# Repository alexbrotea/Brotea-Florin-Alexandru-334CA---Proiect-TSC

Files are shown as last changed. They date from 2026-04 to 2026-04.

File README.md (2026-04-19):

## 1. Diagrama bloc

Mai jos este diagrama bloc a sistemului, ilustrand modul in care componentele interactioneaza cu unitatea centrala (MCU):

```mermaid
graph TD
    BATT[Baterie LiPo] -->|V_BATT| CHG[LiPo Charger MCP73831]
    USB[USB-C Connector] -->|5V| CHG
    CHG --> DCDC[DC/DC Converter]
    DCDC -->|3.3V| MCU(nRF52840 MCU)
    
    BATT -->|Monitorizare| FG[Fuel Gauge MAX17048]
    FG <-->|I2C| MCU
    
    MCU <-->|I2C| IMU[Senzor IMU BMI270]
    MCU <-->|I2C| HAP[Haptic Driver DRV2605L]
    
    MCU <-->|SPI| EPD_CON[E-Paper Display Connector]
    MCU -->|Control| EPD_DRV[E-Paper Drive Circuit]
    
    BTN[Butoane SW_UP, SW_ENT, SW_DN] -->|GPIO| MCU
    SWD[SWD Interface] <-->|Debug| MCU
```
## 2. Bill of Materials

| Componenta / Modul | Rol in proiect | Cod piesa JLCPCB |
|---|---|---|
| nRF52840 | Microcontroler cu Bluetooth LE | C138981 |
| MAX17048G+T10 | Fuel Gauge (monitorizare baterie) | C149814 |
| BMI270 | IMU 6 axe (accelerometru + giroscop) | C2828345 |
| DRV2605L | Driver haptic (LRA/ERM) | C78152 |
| MCP73831T-2ACI/OT | Incarcator LiPo | C14434 |
| TPD4E05U06DQNR | Protectie ESD (USB-C) | C127411 |

## 3. Functionalitate Hardware

InkTime este construit ca un sistem modular eficient energetic:

### Microcontroller (MCU)
- nRF52840 (ARM Cortex-M4F)
- Bluetooth 5 integrat
- Conectivitate directa cu smartphone

### Alimentare si Incarcare
- Incarcare prin USB-C
- Incarcator dedicat LiPo (MCP73831)
- Protectie ESD integrata
- Monitorizare baterie prin MAX17048:
  - Masoara tensiunea
  - Estimeaza procentul bateriei
  - Consum foarte redus

### Afisaj E-Paper
- Conector FPC cu 24 pini
- Circuit dedicat de drive:
  - MOSFET-uri
  - Retea de condensatori
- Genereaza tensiuni pozitive si negative necesare refresh-ului

### Interfata Utilizator
- 3 butoane:
  - SW_UP
  - SW_ENT
  - SW_DN
- Debouncing hardware
- Feedback haptic:
  - Driver DRV2605L
  - Motor vibratii (LRA/ERM)
- IMU pentru detectarea miscarii mainii

## 4. Mapare pini (Pinout nRF52840)
| Periferic | Semnal | Pin MCU | Descriere |
| --- | --- | --- | --- |
| I2C Bus | SDA / SCL | P0.26 / P0.27 | Magistrala comuna pentru senzori |
| E-Paper SPI | SCK / MOSI | P0.17 / P0.20 | Transfer rapid de date |
| E-Paper Control | CS / DC / RST / BUSY | P0.22 / P0.24 / P0.15 / P0.13 | Control display |
| Butoane | SW_UP / SW_ENT / SW_DN | P0.06 / P0.08 / P0.12 | Input cu intreruperi |
| Haptic | EN / IN | P0.05 | Activare driver haptic |
| USB Sense | VBUS | P0.02 | Detectare cablu USB |

## 5. Design Log & Review
- Placa pe 2 straturi
- Forma ergonomica adaptata carcasei
- Plan de masa optimizat pentru:
stabilitate RF
performanta Bluetooth
- Grosime minimizata
- Layout compact
- Integrare eficienta

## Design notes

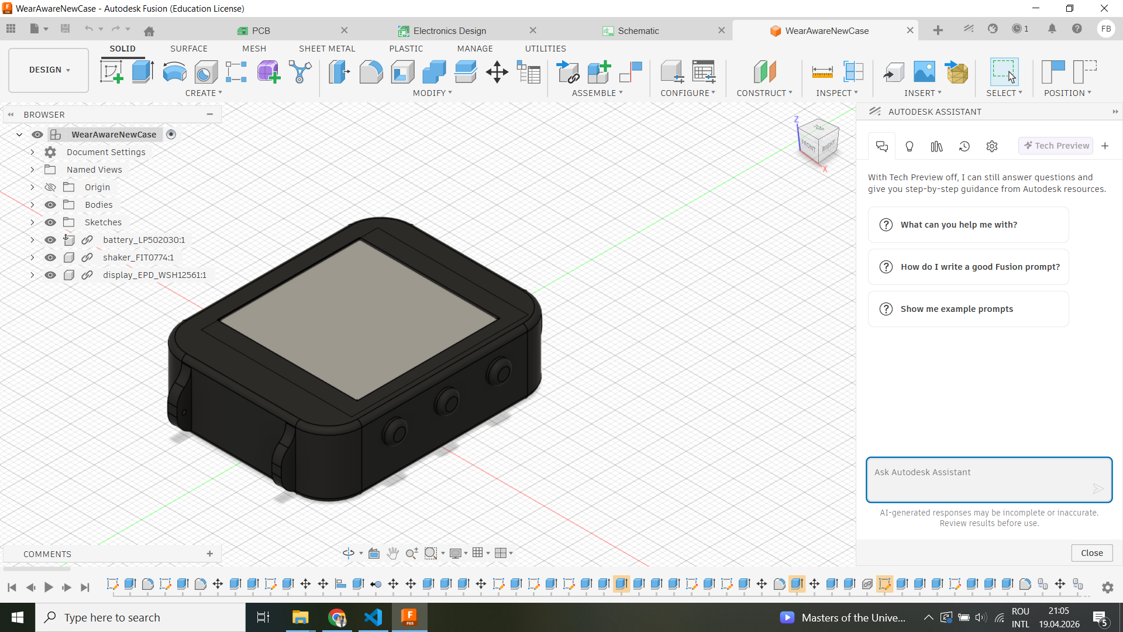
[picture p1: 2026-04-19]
Images/Screenshot (1024).png

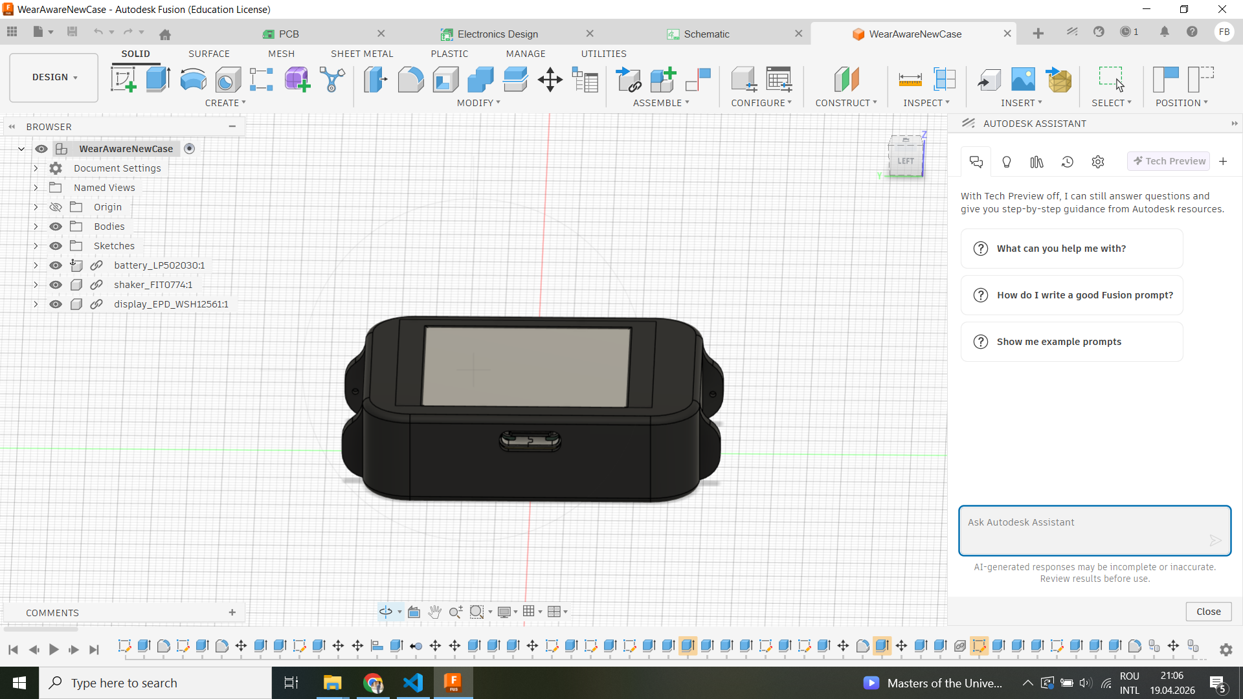
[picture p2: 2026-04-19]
Images/Screenshot (1026).png

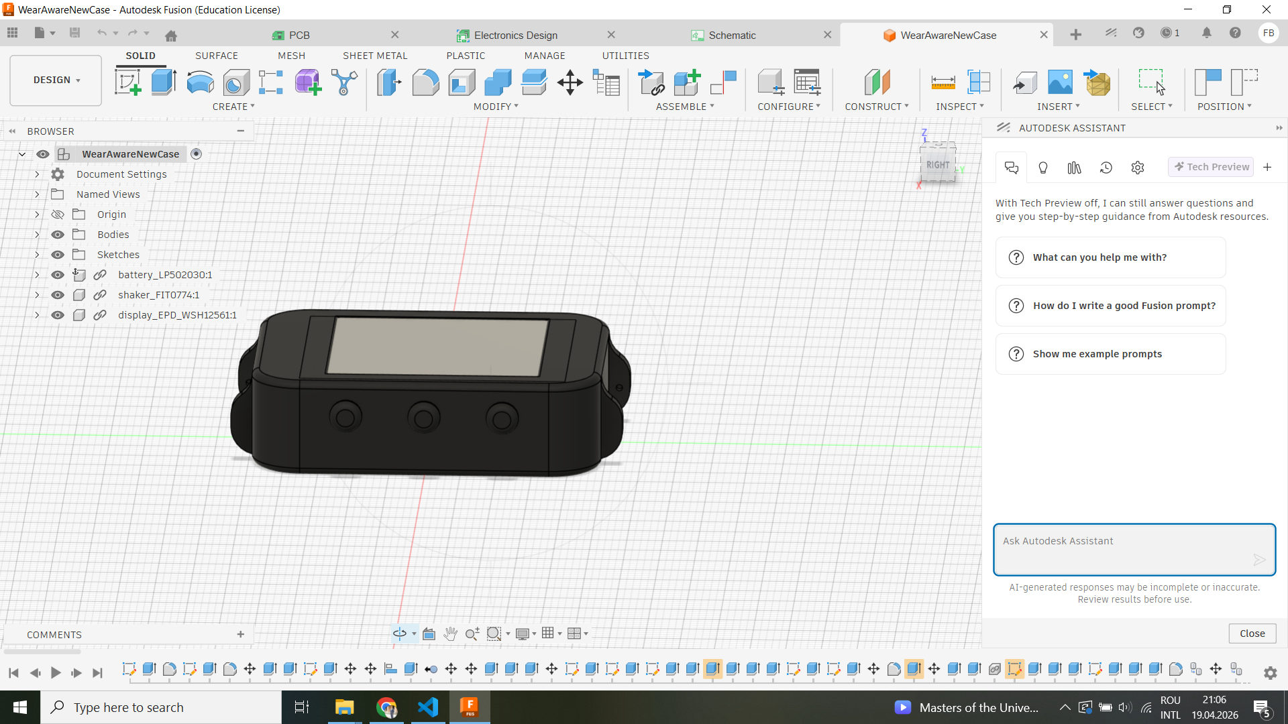
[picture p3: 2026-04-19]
Images/Screenshot (1027).png

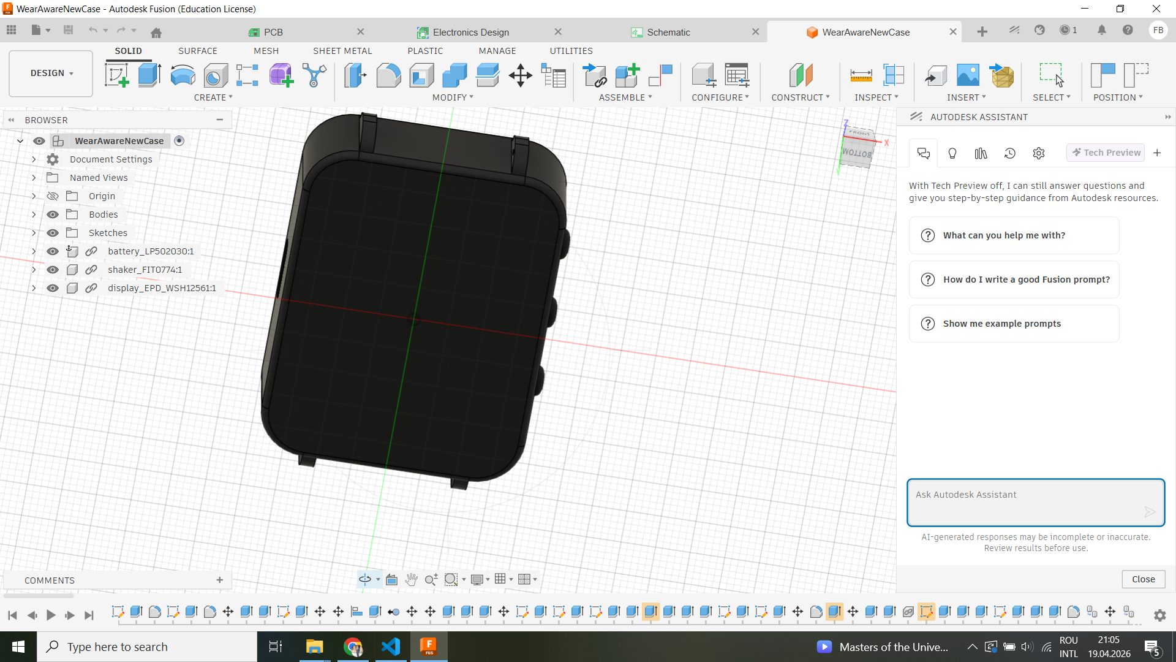
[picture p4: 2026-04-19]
Images/Screenshot (1025).png

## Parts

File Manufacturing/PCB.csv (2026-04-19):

Qty | Value | Device | Package | Parts | Description | ARROW_PART_NUMBER | ARROW_PRICE-STOCK | AVAILABILITY | CHECK_PRICES | COPYRIGHT | DESCRIPTION | DIGI-KEY_PART_NUMBER_1 | DIGI-KEY_PART_NUMBER_2 | DIGI-KEY_PART_NUMBER_3 | HEIGHT | JLCPCB | MANUFACTURER_NAME | MANUFACTURER_PART_NUMBER | MF | MFR_NAME | MOUSER_PART_NUMBER | MOUSER_PRICE-STOCK | MP | PACKAGE | POPULARITY | PRICE | PROD_ID | PURCHASE-URL | SNAPEDA_LINK | SPICEMODEL | SPICEPREFIX | TP_SIGNAL_NAME | VALUE
1 | 0 | ESP32_C6_LIBRARY_7_JUMPER_SJ | ESP32_C6_LIBRARY_7_JUMPER_SJ | SJ1 | SMD solder JUMPER |  |  |  |  |  |  |  |  |  |  |  |  |  |  |  |  |  |  |  | 3
1 | 0.1uF | GRM011R60J152KE01L_1_GRM011R60J152KE01L | GRM011R60J152KE01L_1_0201 | C4 | Check availability
1 | 0.1uF | NORDIC_NRF_3_CAPACITOR_0402_M | NORDIC_NRF_3_RESC0402_M | C23 | Generic chip capacitor
1 | 0.1uF/50V | NORDIC_NRF_3_CAPACITOR_0402_M | NORDIC_NRF_3_RESC0402_M | EPD_C5 | Generic chip capacitor
4 | 100nF | NORDIC_NRF_3_CAPACITOR_0402_M | NORDIC_NRF_3_RESC0402_M | C7, C8, CC5, CC19 | Generic chip capacitor
2 | 100pF | NORDIC_NRF_3_CAPACITOR_0402_M | NORDIC_NRF_3_RESC0402_M | C12, CC11 | Generic chip capacitor
1 | 10K | CPF0201D7K68C1_CPF0201D7K68C1 | CPF0201D7K68C1_0201 | R1 | 7.68k 0201 Thin Film Surface Mount Fixed Resistor +/-0.5% 0.031W CPF0201D7K68C1
3 | 10uF | NORDIC_NRF_3_CAPACITOR_0402_M | NORDIC_NRF_3_RESC0402_M | C1-EP-DR, C24, C39 | Generic chip capacitor
1 | 10uH | NORDIC_NRF_2_INDUCTOR_0402_M | NORDIC_NRF_2_RESC0402_M | LL2 | Generic chip inductor
4 | 12pF | NORDIC_NRF_3_CAPACITOR_0402_M | NORDIC_NRF_3_RESC0402_M | C17, C18, CC1, CC2 | Generic chip capacitor
1 | 15uH | NORDIC_NRF_2_INDUCTOR_0402_M | NORDIC_NRF_2_RESC0402_M | LL3 | Generic chip inductor
2 | 1pF | NORDIC_NRF_3_CAPACITOR_0402_M | NORDIC_NRF_3_RESC0402_M | CC3, CC4 | Generic chip capacitor
1 | 1uF | GRM011R60J152KE01L_1_GRM011R60J152KE01L | GRM011R60J152KE01L_1_0201 | C3 | Check availability
3 | 1uF | NORDIC_NRF_3_CAPACITOR_0402_M | NORDIC_NRF_3_RESC0402_M | C15, C37, C38 | Generic chip capacitor
9 | 1uF/50V | NORDIC_NRF_3_CAPACITOR_0402_M | NORDIC_NRF_3_RESC0402_M | EPD_C1, EPD_C2, EPD_C6, EPD_C7, EPD_C8, EPD_C9, EPD_C10, EPD_C11, EPD_C12 | Generic chip capacitor
3 | 2025-10-22_07-23-44_LIBRARY_EVP-AKE31ASW_EVP-AKE31A_PAN | 2025-10-22_07-23-44_LIBRARY_EVP-AKE31ASW_EVP-AKE31A_PAN | 2025-10-22_07-23-44_LIBRARY_SW_EVP-AKE31A_PAN | SW1, SW2, SW3 |  |  |  |  |  | Copyright (C) 2025 Ultra Librarian. All rights reserved. |  | P123437TR-ND | P123437CT-ND | P123437DKR-ND |  |  | Panasonic | EVP-AKE31A
1 | 20V/4.2A/52m?/1.4W | ESP32_C6_LIBRARY_4_ESP32_WROVER_SPARKFUN-DISCRETESEMI_MOSFET_PCH-DMG2305UX-7 | ESP32_C6_LIBRARY_4_ESP32_C6_LIBRARY_4_ESP32_C6_LIBRARY_4_ESP32_C6_LIBRARY_4_ESP32_WROVER_SPARKFUN-DISCRETESEMI_SOT23-3 | Q1 | P-channel MOSFETs |  |  |  |  |  |  |  |  |  |  |  |  |  |  |  |  |  |  |  |  |  | TRAN-14388 |  |  |  |  |  | 20V/4.2A/52m?/1.4W
2 | 22uF | NORDIC_NRF_3_CAPACITOR_0402_M | NORDIC_NRF_3_RESC0402_M | C25, C33 | Generic chip capacitor
1 | 2450AT18B100E_2450AT18B100E | 2450AT18B100E_2450AT18B100E | 2450AT18B100E_ANTC3216X140N | ANT1 | Antennas 2.45GHz ANTENNA | 2450AT18B100E | https://www.arrow.com/en/products/2450at18b100e/johanson-dielectrics?utm_currency=USD&region=nac |  |  |  | Antennas 2.45GHz ANTENNA |  |  |  | 1.4mm |  | JOHANSON TECHNOLOGY | 2450AT18B100E |  |  | 609-2450AT18B100E | https://www.mouser.co.uk/ProductDetail/Johanson-Technology/2450AT18B100E?qs=yCnrNFeXz%252Bh5MFsFIXGZGA%3D%3D
1 | 3.9nH | NORDIC_NRF_2_INDUCTOR_0402_M | NORDIC_NRF_2_RESC0402_M | LL1 | Generic chip inductor
1 | 32.768KHz | NORDIC_NRF_1_XTAL_32KHZ | NORDIC_NRF_1_XTAL_3215_N | X2
1 | 32MHz | NORDIC_NRF_XTAL_32MHZ | NORDIC_NRF_BT-XTAL_2016_N | X1
5 | 4.7uF | NORDIC_NRF_3_CAPACITOR_0402_M | NORDIC_NRF_3_RESC0402_M | C6, C20, C21, C43, CC14 | Generic chip capacitor
1 | 4.7uF/25V | ESP32_C6_LIBRARY_1_ESP32_WROVER_EAGLE-LTSPICE_CC0402 | ESP32_C6_LIBRARY_1_ESP32_WROVER_EAGLE-LTSPICE_C0402 | C2-EP-DR | CAPACITOR, European symbol |  |  |  |  |  |  |  |  |  |  |  |  |  |  |  |  |  |  |  |  |  |  |  |  | NONE | C
1 | 47nF | NORDIC_NRF_3_CAPACITOR_0402_M | NORDIC_NRF_3_RESC0402_M | C16 | Generic chip capacitor
1 | 503480-2400_503480-2400 | 503480-2400_503480-2400 | 503480-2400_5034802400 | J2 | FFC & FPC Connectors 0.5mm FPC RA SMT Dual Contact 24Ckt |  |  |  |  |  | FFC & FPC Connectors 0.5mm FPC RA SMT Dual Contact 24Ckt |  |  |  | 1.87mm |  | Molex | 503480-2400 |  |  | 538-503480-2400 | https://www.mouser.co.uk/ProductDetail/Molex/503480-2400?qs=OAhjpuo3Vu7efIoxFh9AOw%3D%3D
1 | 820pF | NORDIC_NRF_3_CAPACITOR_0402_M | NORDIC_NRF_3_RESC0402_M | C9 | Generic chip capacitor
1 | BMA423_BMA423 | BMA423_BMA423 | BMA423_BMA423 | IC3 | Accelerometers Triaxial low-g 12bit Acceleration Sensor | BMA423 | https://www.arrow.com/en/products/bma423/bosch |  |  |  | Accelerometers Triaxial low-g 12bit Acceleration Sensor |  |  |  | 1mm |  | BOSCH | BMA423 |  |  | 262-BMA423 | https://www.mouser.co.uk/ProductDetail/Bosch-Sensortec/BMA423?qs=HXFqYaX1Q2xC%252BSgeGoX3mg%3D%3D
1 | BQ25180YBGR_BQ25180YBGR | BQ25180YBGR_BQ25180YBGR | BQ25180YBGR_BGA8C40P2X4_100X155X50 | IC1 | Charger IC Lithium Ion/Polymer, Lithium Iron Phosphate 8-DSBGA (1.6x1.1) | BQ25180YBGR | https://www.arrow.com/en/products/bq25180ybgr/texas-instruments?utm_currency=USD&region=nac |  |  |  | Charger IC Lithium Ion/Polymer | Lithium Iron Phosphate 8-DSBGA (1.6x1.1) |  |  |  | 0.5mm |  | Texas Instruments | BQ25180YBGR |  |  | 595-BQ25180YBGR | https://www.mouser.co.uk/ProductDetail/Texas-Instruments/BQ25180YBGR?qs=doiCPypUmgEWjAK%252BJAX6Tw%3D%3D
14 | CPF0201D7K68C1_CPF0201D7K68C1 | CPF0201D7K68C1_CPF0201D7K68C1 | CPF0201D7K68C1_0201 | R2, R3, R4, R5, R6, R7, R8, R9, R10, R11, R12, R13, R14, R15 | 7.68k 0201 Thin Film Surface Mount Fixed Resistor +/-0.5% 0.031W CPF0201D7K68C1
1 | DRV2605YZFR_DRV2605YZFR | DRV2605YZFR_DRV2605YZFR | DRV2605YZFR_BGA9C50P3X3_144X144X62 | IC4 | Haptic Driver for ERM/LRA with Built-In Library and Smart Loop Architecture | DRV2605YZFR | https://www.arrow.com/en/products/drv2605yzfr/texas-instruments?region=nac |  |  |  | Haptic Driver for ERM/LRA with Built-In Library and Smart Loop Architecture |  |  |  | 0.625mm |  | Texas Instruments | DRV2605YZFR
1 | ESP32_C6_LIBRARY_2_744043680IND_4828-WE-TPC_WRE | ESP32_C6_LIBRARY_2_744043680IND_4828-WE-TPC_WRE | ESP32_C6_LIBRARY_2_IND_4828-WE-TPC_WRE | L2 |  |  |  |  |  | Copyright (C) 2024 Ultra Librarian. All rights reserved. |  |  |  |  |  |  |  | 744043680 |  | Wurth Electronics
1 | ESP32_C6_LIBRARY_3_USBLC6-2SC6Y | ESP32_C6_LIBRARY_3_USBLC6-2SC6Y | ESP32_C6_LIBRARY_3_SOT95P280X145-6N | D4 | Low Cap. ESD Protection Auto SOT-23-6 STMicroelectronics USBLC6-2SC6Y, Dual Uni-Directional TVS Diode Array, 6-Pin SOT-23 |  |  | In Stock | https://www.snapeda.com/parts/USBLC6-2SC6Y/STMicroelectronics/view-part/?ref=eda |  | 17V Clamp 5A (8/20µs) Ipp Tvs Diode Surface Mount SOT-23-6 |  |  |  |  |  |  |  | STMicroelectronics |  |  |  | USBLC6-2SC6Y | SOT-23-6 STMicroelectronics |  | None |  |  | https://www.snapeda.com/parts/USBLC6-2SC6Y/STMicroelectronics/view-part/?ref=snap
3 | ESP32_C6_LIBRARY_5_MBR0530 | ESP32_C6_LIBRARY_5_MBR0530 | ESP32_C6_LIBRARY_5_SOD3716X135N | D1, D2, D3 | ON SEMICONDUCTOR - MBR0530 - DIODE, SCHOTTKY, 0.5A, 30V, SOD-123 |  |  | In Stock | https://www.snapeda.com/parts/MBR0530/Onsemi/view-part/?ref=eda |  | Diode Schottky 30 V 500mA Surface Mount SOD-123 |  |  |  |  |  |  |  | ON Semiconductor |  |  |  | MBR0530 | SOD-123-2 ON Semiconductor |  | None |  | https://www.snapeda.com/api/url_track_click_mouser/?unipart_id=179458&manufacturer=ON Semiconductor&part_name=MBR0530&search_term=None | https://www.snapeda.com/parts/MBR0530/Onsemi/view-part/?ref=snap
1 | ESP32_C6_LIBRARY_6_SI1308EDL-T1-GE3 | ESP32_C6_LIBRARY_6_SI1308EDL-T1-GE3 | ESP32_C6_LIBRARY_6_SOT65P210X110-3N | Q2 | MOSFET N-Ch 30V 1.5A TrenchFET SC70 Vishay Si1308EDL-T1-GE3 N-channel MOSFET Transistor, 1.5 A, 30 V, 3-Pin SC-70 |  |  | In Stock | https://www.snapeda.com/parts/SI1308EDL-T1-GE3/Vishay+Siliconix/view-part/?ref=eda |  | Si1308EDL-T1-GE3 N-channel MOSFET Transistor | 1.5 A | 30 V | 3-Pin SC-70 | Siliconix / Vishay SI1308EDL-T1-GE3 |  |  |  |  |  |  |  | Vishay Siliconix |  |  |  | SI1308EDL-T1-GE3 | SOT-323 Vishay Semiconductor |  | None |  | https://www.snapeda.com/api/url_track_click_mouser/?unipart_id=274603&manufacturer=Vishay Siliconix&part_name=SI1308EDL-T1-GE3&search_term=None | https://www.snapeda.com/parts/SI1308EDL-T1-GE3/Vishay+Siliconix/view-part/?ref=snap
1 | ESP32_C6_LIBRARY_MAX17048G+T10 | ESP32_C6_LIBRARY_MAX17048G+T10 | ESP32_C6_LIBRARY_SON50P200X200X80-9N | U1 | Check availability |  |  | In Stock | https://www.snapeda.com/parts/MAX17048G+T10/Analog+Devices/view-part/?ref=eda |  | 3µA 1-Cell/2-Cell Fuel Gauge with ModelGauge |  |  |  |  |  |  |  | Analog Devices |  |  |  | MAX17048G+T10 | TDFN-8 Maxim |  | None |  | https://www.snapeda.com/api/url_track_click_mouser/?unipart_id=329239&manufacturer=Analog Devices&part_name=MAX17048G+T10&search_term=None | https://www.snapeda.com/parts/MAX17048G+T10/Analog+Devices/view-part/?ref=snap
5 | GRM011R60J152KE01L_1_GRM011R60J152KE01L | GRM011R60J152KE01L_1_GRM011R60J152KE01L | GRM011R60J152KE01L_1_0201 | C2, C5, C10, C11, C42 | Check availability
14 | HECTOR_WATCH_1_TPTP20R | HECTOR_WATCH_1_TPTP20R | HECTOR_WATCH_1_TP20R | TP_3V3, TP_SCL, TP_SDA, TP_SDA1, TP_SDA2, TP_SDA3, TP_SDA4, TP_SDA5, TP_SDA6, TP_SDA7, TP_SDA8, TP_SDA9, TP_SDA10, TP_VREG | Test pad |  |  |  |  |  |  |  |  |  |  |  |  |  |  |  |  |  |  |  | 2
1 | KH-TYPE-C-16P_KH-TYPE-C-16P | KH-TYPE-C-16P_KH-TYPE-C-16P | KH-TYPE-C-16P_KINGHELM_KH-TYPE-C-16P | J3 | Check availability |  |  | Not in stock | https://www.snapeda.com/parts/KH-TYPE-C-16P/Kinghelm/view-part/?ref=eda |  |  |  |  |  |  |  |  |  | kinghelm |  |  |  | KH-TYPE-C-16P | None |  | None |  |  | https://www.snapeda.com/parts/KH-TYPE-C-16P/Kinghelm/view-part/?ref=snap
1 | MLP2016SR47MT0S1_FTC252012SR47MBCA | MLP2016SR47MT0S1_FTC252012SR47MBCA | MLP2016SR47MT0S1_INDC2016X100N | L1 | SMD / SMT Inductors (Coils), L=0.47?H, L x W x T : |  |  |  |  |  | SMD / SMT Inductors (Coils) | L=0.47?H | L x W x T : |  |  |  | 1mm | https://jlcpcb.com/partdetail/6763488-FTC252012SR47MBCA/C5832368 | TDK | FTC252012SR47MBCA
3 | N.C | NORDIC_NRF_3_CAPACITOR_0402_M | NORDIC_NRF_3_RESC0402_M | C13, CC10, CC22 | Generic chip capacitor
1 | NORDIC_NRF_4_NRF52840_QF | NORDIC_NRF_4_NRF52840_QF | NORDIC_NRF_4_AQFN50P700X700X85_HS-74N | P1.01/2.4B | nRF52840
1 | RT6160AWSC_RT6160AWSC | RT6160AWSC_RT6160AWSC | RT6160AWSC_BGA15C40P3X5_140X230X60 | IC2 | Buck-Boost Regulator Positive Output Step-Up/Step-Down I2C DC-DC Controller IC 15-WL-CSP (BSC) (1.4x2.3) |  |  |  |  |  | Buck-Boost Regulator Positive Output Step-Up/Step-Down I2C DC-DC Controller IC 15-WL-CSP (BSC) (1.4x2.3) |  |  |  | 0.6mm |  | RICHTEK | RT6160AWSC |  |  | 835-RT6160AWSC | https://www.mouser.co.uk/ProductDetail/Richtek/RT6160AWSC?qs=amGC7iS6iy%2FLd9PSoixZXQ%3D%3D
1 | TC2030-IDC_TC2030-IDC | TC2030-IDC_TC2030-IDC | TC2030-IDC_TC2030IDC | J1 | CABLE ADAPTER 6 POS |  |  |  |  |  | CABLE ADAPTER 6 POS |  |  |  | 19mm |  | Tag Connect | TC2030-IDC

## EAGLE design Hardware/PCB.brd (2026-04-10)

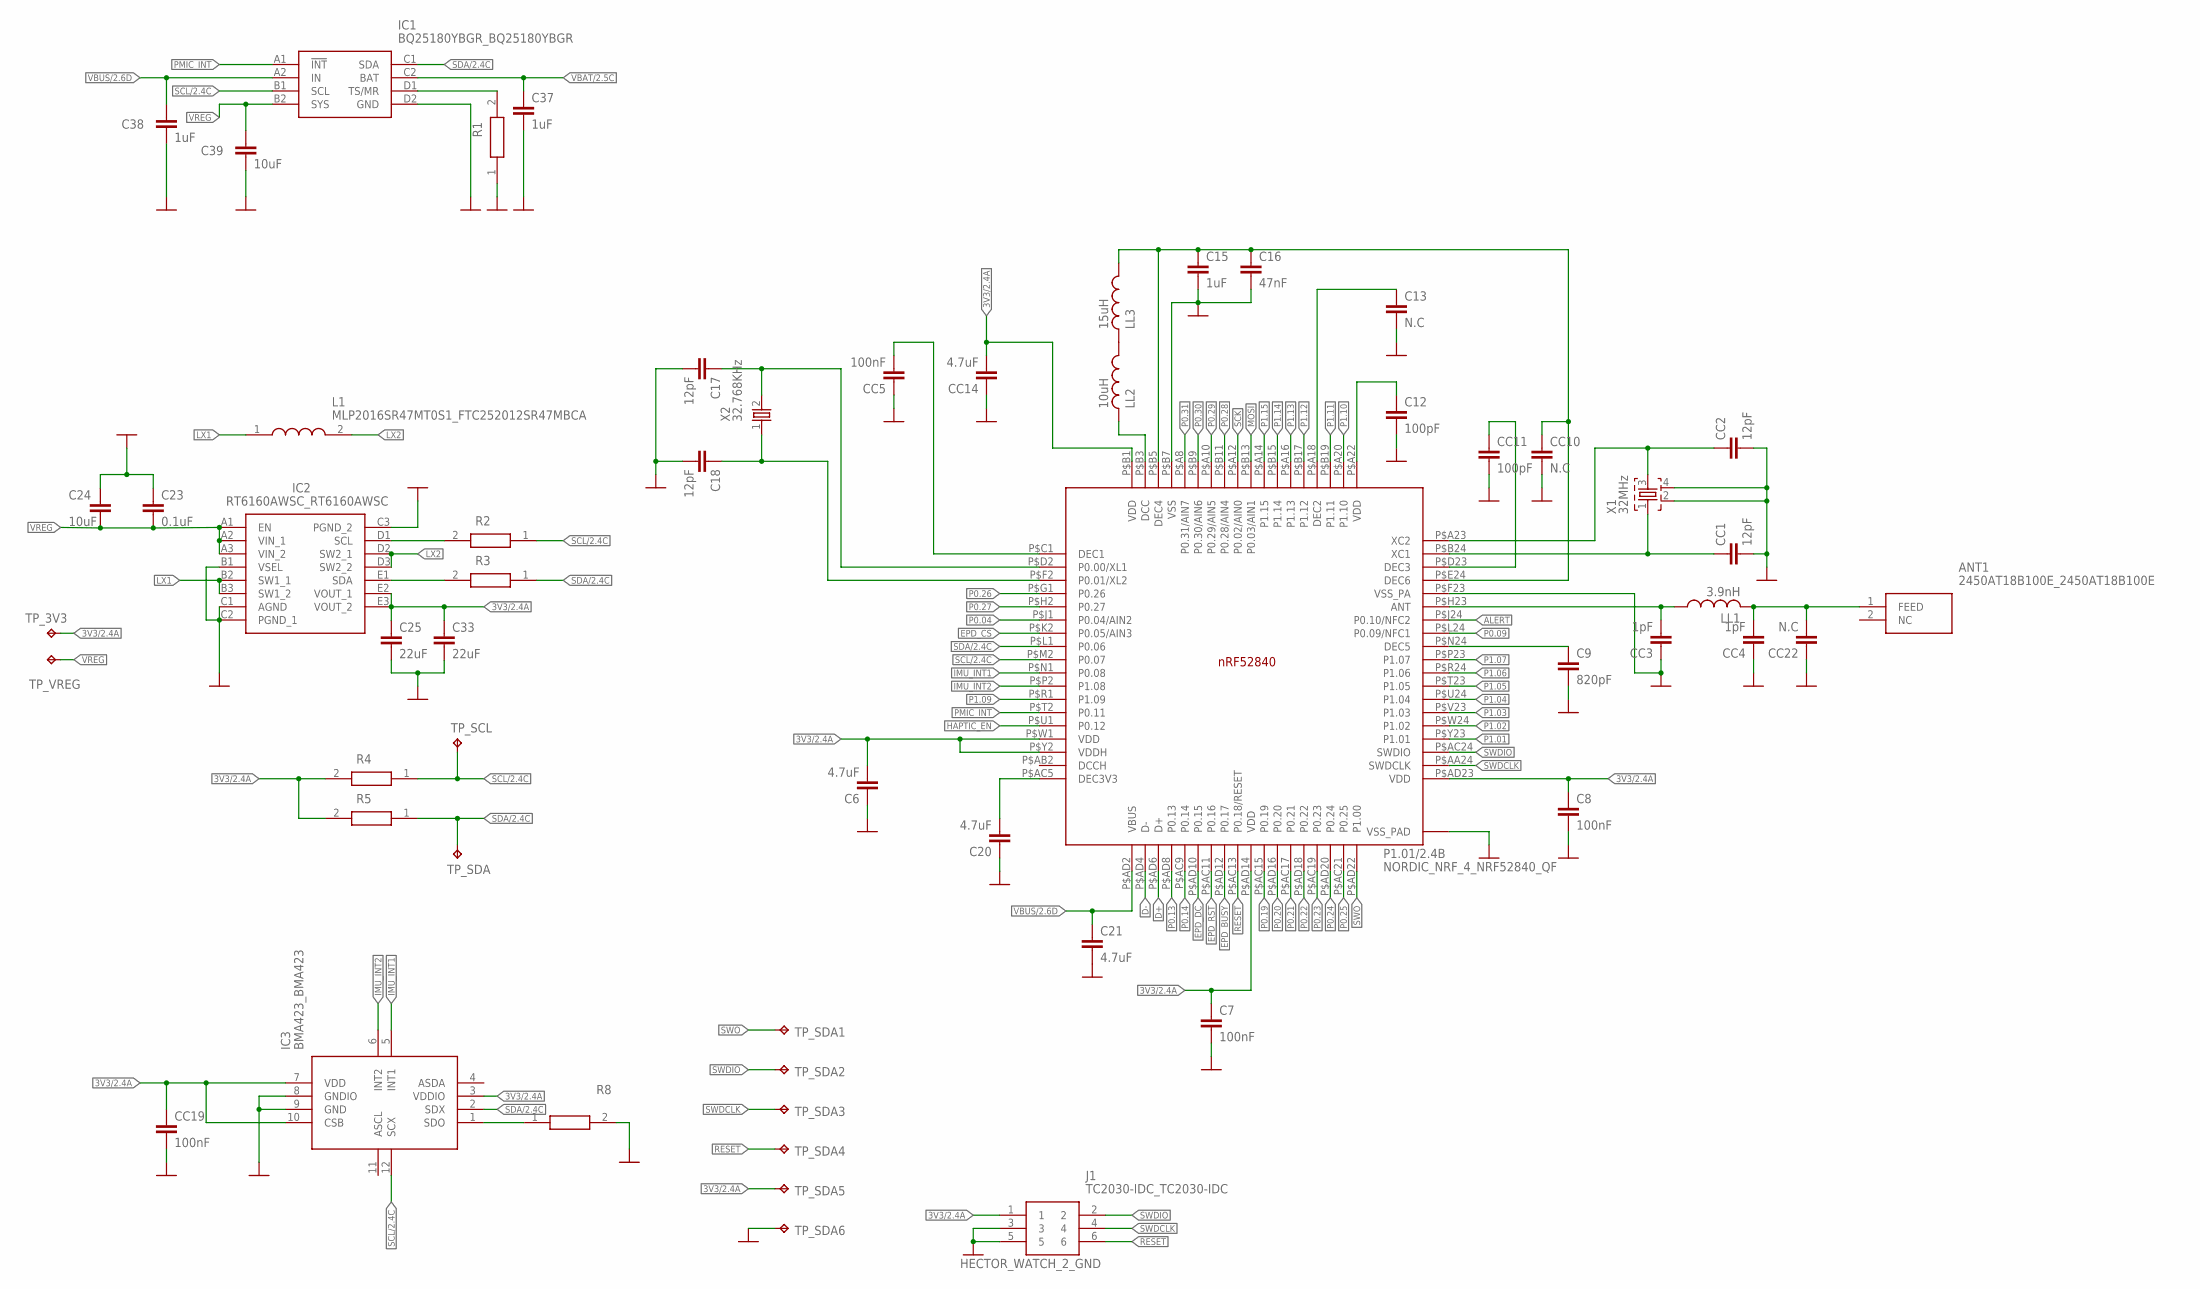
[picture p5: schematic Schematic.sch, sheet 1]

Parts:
ANT1: 2450AT18B100E_2450AT18B100E; 2450AT18B100E_ANTC3216X140N
C6, C20, C21: 4.7uF; NORDIC_NRF_3_RESC0402_M
C7, C8: 100nF; NORDIC_NRF_3_RESC0402_M
C9: 820pF; NORDIC_NRF_3_RESC0402_M
C12: 100pF; NORDIC_NRF_3_RESC0402_M
C13: N.C; NORDIC_NRF_3_RESC0402_M
C15, C37, C38: 1uF; NORDIC_NRF_3_RESC0402_M
C16: 47nF; NORDIC_NRF_3_RESC0402_M
C17, C18: 12pF; NORDIC_NRF_3_RESC0402_M
C23: 0.1uF; NORDIC_NRF_3_RESC0402_M
C24, C39: 10uF; NORDIC_NRF_3_RESC0402_M
C25, C33: 22uF; NORDIC_NRF_3_RESC0402_M
CC1, CC2: 12pF; NORDIC_NRF_3_RESC0402_M
CC3, CC4: 1pF; NORDIC_NRF_3_RESC0402_M
CC5, CC19: 100nF; NORDIC_NRF_3_RESC0402_M
CC10, CC22: N.C; NORDIC_NRF_3_RESC0402_M
CC11: 100pF; NORDIC_NRF_3_RESC0402_M
CC14: 4.7uF; NORDIC_NRF_3_RESC0402_M
IC1: BQ25180YBGR_BQ25180YBGR; BQ25180YBGR_BGA8C40P2X4_100X155X50
IC2: RT6160AWSC_RT6160AWSC; RT6160AWSC_BGA15C40P3X5_140X230X60
IC3: BMA423_BMA423
J1: TC2030-IDC_TC2030-IDC; TC2030-IDC_TC2030IDC
L1: MLP2016SR47MT0S1_FTC252012SR47MBCA; MLP2016SR47MT0S1_INDC2016X100N
LL1: 3.9nH; NORDIC_NRF_2_RESC0402_M
LL2: 10uH; NORDIC_NRF_2_RESC0402_M
LL3: 15uH; NORDIC_NRF_2_RESC0402_M
P1.01/2.4B: NORDIC_NRF_4_NRF52840_QF; NORDIC_NRF_4_AQFN50P700X700X85_HS-74N
R1: 10K; CPF0201D7K68C1_0201
R2, R3, R4, R5, R8: CPF0201D7K68C1_CPF0201D7K68C1; CPF0201D7K68C1_0201
TP_3V3: HECTOR_WATCH_1_TPTP20R; HECTOR_WATCH_1_TP20R
TP_SCL: HECTOR_WATCH_1_TPTP20R; HECTOR_WATCH_1_TP20R
TP_SDA, TP_SDA1, TP_SDA2, TP_SDA3, TP_SDA4, TP_SDA5, TP_SDA6: HECTOR_WATCH_1_TPTP20R; HECTOR_WATCH_1_TP20R
TP_VREG: HECTOR_WATCH_1_TPTP20R; HECTOR_WATCH_1_TP20R
X1: 32MHz; NORDIC_NRF_BT-XTAL_2016_N
X2: 32.768KHz; NORDIC_NRF_1_XTAL_3215_N

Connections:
3V3/2.4A: C6.2, C7.1, C8.1, C25.1, C33.1, CC14.2, CC19.1, IC2.E2 (VOUT_1), IC2.E3 (VOUT_2), IC3.3 (VDDIO), IC3.7 (VDD), IC3.10 (CSB), J1.1, P1.01/2.4B.P$AD14 (VDD), P1.01/2.4B.P$AD23 (VDD), P1.01/2.4B.P$B1 (VDD), P1.01/2.4B.P$W1 (VDD), P1.01/2.4B.P$Y2 (VDDH), R4.2, R5.2, TP_3V3.TP, TP_SDA5.TP
ALERT: P1.01/2.4B.P$J24 (P0.10/NFC2); also elsewhere on the board
D+: P1.01/2.4B.P$AD6 (D+); also elsewhere on the board
D-: P1.01/2.4B.P$AD4 (D-); also elsewhere on the board
EPD_BUSY: P1.01/2.4B.P$AD12 (P0.17); also elsewhere on the board
EPD_CS: P1.01/2.4B.P$K2 (P0.05/AIN3); also elsewhere on the board
EPD_DC: P1.01/2.4B.P$AD10 (P0.15); also elsewhere on the board
EPD_RST: P1.01/2.4B.P$AC11 (P0.16); also elsewhere on the board
GND: C6.1, C7.2, C8.2, C9.2, C12.2, C13.2, C15.2, C16.2, C17.2, C18.2, C20.1, C21.2, C23.1, C24.1, C25.2, C33.2, C37.2, C38.2, C39.2, CC1.2, CC2.2, CC3.1, CC4.1, CC5.1, CC10.2, CC11.2, CC14.1, CC19.2, CC22.1, IC1.D2 (GND), IC2.B1 (VSEL), IC2.C1 (AGND), IC2.C2 (PGND_1), IC2.C3 (PGND_2), IC3.8 (GNDIO), IC3.9 (GND), J1.3, J1.5, P1.01/2.4B.P$74 (VSS_PAD), P1.01/2.4B.P$75 (VSS_PAD), P1.01/2.4B.P$76 (VSS_PAD), P1.01/2.4B.P$77 (VSS_PAD), P1.01/2.4B.P$78 (VSS_PAD), P1.01/2.4B.P$79 (VSS_PAD), P1.01/2.4B.P$80 (VSS_PAD), P1.01/2.4B.P$81 (VSS_PAD), P1.01/2.4B.P$82 (VSS_PAD), P1.01/2.4B.P$83 (VSS_PAD), P1.01/2.4B.P$84 (VSS_PAD), P1.01/2.4B.P$85 (VSS_PAD), P1.01/2.4B.P$86 (VSS_PAD), P1.01/2.4B.P$87 (VSS_PAD), P1.01/2.4B.P$88 (VSS_PAD), P1.01/2.4B.P$89 (VSS_PAD), P1.01/2.4B.P$90 (VSS_PAD), P1.01/2.4B.P$B7 (VSS), P1.01/2.4B.P$F23 (VSS_PA), R1.1, R8.2, TP_SDA6.TP, X1.2, X1.4; also elsewhere on the board
HAPTIC_EN: P1.01/2.4B.P$U1 (P0.12); also elsewhere on the board
IMU_INT1: IC3.5 (INT1), P1.01/2.4B.P$N1 (P0.08)
IMU_INT2: IC3.6 (INT2), P1.01/2.4B.P$P2 (P1.08)
LX1: IC2.B2 (SW1_1), IC2.B3 (SW1_2), L1.1
LX2: IC2.D2 (SW2_1), IC2.D3 (SW2_2), L1.2
MOSI: P1.01/2.4B.P$B13 (P0.03/AIN1); also elsewhere on the board
unnamed: IC1.D1 (TS/MR), R1.2
unnamed: C9.1, P1.01/2.4B.P$N24 (DEC5)
unnamed: CC3.2, LL1.1, P1.01/2.4B.P$H23 (ANT)
unnamed: IC2.D1 (SCL), R2.2
unnamed: IC2.E1 (SDA), R3.2
unnamed: C20.2, P1.01/2.4B.P$AC5 (DEC3V3)
unnamed: ANT1.1 (FEED), CC4.2, CC22.2, LL1.2
unnamed: CC1.1, P1.01/2.4B.P$B24 (XC1), X1.1
unnamed: CC2.1, P1.01/2.4B.P$A23 (XC2), X1.3
unnamed: CC11.1, P1.01/2.4B.P$D23 (DEC3)
unnamed: C18.1, P1.01/2.4B.P$F2 (P0.01/XL2), X2.1
unnamed: C12.1, P1.01/2.4B.P$A22 (VDD)
unnamed: C13.1, P1.01/2.4B.P$A18 (DEC2)
unnamed: LL2.1, LL3.2
unnamed: LL2.2, P1.01/2.4B.P$B3 (DCC)
unnamed: C15.1, C16.1, CC10.1, LL3.1, P1.01/2.4B.P$B5 (DEC4), P1.01/2.4B.P$E24 (DEC6)
unnamed: C17.1, P1.01/2.4B.P$D2 (P0.00/XL1), X2.2
unnamed: IC3.1 (SDO), R8.1
unnamed: CC5.2, P1.01/2.4B.P$C1 (DEC1)
P0.04: P1.01/2.4B.P$J1 (P0.04/AIN2)
P0.09: P1.01/2.4B.P$L24 (P0.09/NFC1)
P0.13: P1.01/2.4B.P$AD8 (P0.13); also elsewhere on the board
P0.14: P1.01/2.4B.P$AC9 (P0.14); also elsewhere on the board
P0.19: P1.01/2.4B.P$AC15 (P0.19)
P0.20: P1.01/2.4B.P$AD16 (P0.20)
P0.21: P1.01/2.4B.P$AC17 (P0.21)
P0.22: P1.01/2.4B.P$AD18 (P0.22)
P0.23: P1.01/2.4B.P$AC19 (P0.23)
P0.24: P1.01/2.4B.P$AD20 (P0.24)
P0.25: P1.01/2.4B.P$AC21 (P0.25)
P0.26: P1.01/2.4B.P$G1 (P0.26)
P0.27: P1.01/2.4B.P$H2 (P0.27)
P0.28: P1.01/2.4B.P$B11 (P0.28/AIN4)
P0.29: P1.01/2.4B.P$A10 (P0.29/AIN5)
P0.30: P1.01/2.4B.P$B9 (P0.30/AIN6)
P0.31: P1.01/2.4B.P$A8 (P0.31/AIN7)
P1.01: P1.01/2.4B.P$Y23 (P1.01); also elsewhere on the board
P1.02: P1.01/2.4B.P$W24 (P1.02); also elsewhere on the board
P1.03: P1.01/2.4B.P$V23 (P1.03)
P1.04: P1.01/2.4B.P$U24 (P1.04)
P1.05: P1.01/2.4B.P$T23 (P1.05)
P1.06: P1.01/2.4B.P$R24 (P1.06)
P1.07: P1.01/2.4B.P$P23 (P1.07)
P1.09: P1.01/2.4B.P$R1 (P1.09)
P1.10: P1.01/2.4B.P$A20 (P1.10)
P1.11: P1.01/2.4B.P$B19 (P1.11)
P1.12: P1.01/2.4B.P$B17 (P1.12)
P1.13: P1.01/2.4B.P$A16 (P1.13)
P1.14: P1.01/2.4B.P$B15 (P1.14)
P1.15: P1.01/2.4B.P$A14 (P1.15)
PMIC_INT: IC1.A1 (!INT), P1.01/2.4B.P$T2 (P0.11)
RESET: J1.6, P1.01/2.4B.P$AC13 (P0.18/RESET), TP_SDA4.TP
SCK: P1.01/2.4B.P$A12 (P0.02/AIN0); also elsewhere on the board
SCL/2.4C: IC1.B1 (SCL), IC3.12 (SCX), P1.01/2.4B.P$M2 (P0.07), R2.1, R4.1, TP_SCL.TP
SDA/2.4C: IC1.C1 (SDA), IC3.2 (SDX), P1.01/2.4B.P$L1 (P0.06), R3.1, R5.1, TP_SDA.TP
SWDCLK: J1.4, P1.01/2.4B.P$AA24 (SWDCLK), TP_SDA3.TP
SWDIO: J1.2, P1.01/2.4B.P$AC24 (SWDIO), TP_SDA2.TP
SWO: P1.01/2.4B.P$AD22 (P1.00), TP_SDA1.TP
VBAT/2.5C: C37.1, IC1.C2 (BAT)
VBUS/2.6D: C21.1, C38.1, IC1.A2 (IN), P1.01/2.4B.P$AD2 (VBUS)
VREG: C23.2, C24.2, C39.1, IC1.B2 (SYS), IC2.A1 (EN), IC2.A2 (VIN_1), IC2.A3 (VIN_2), TP_VREG.TP

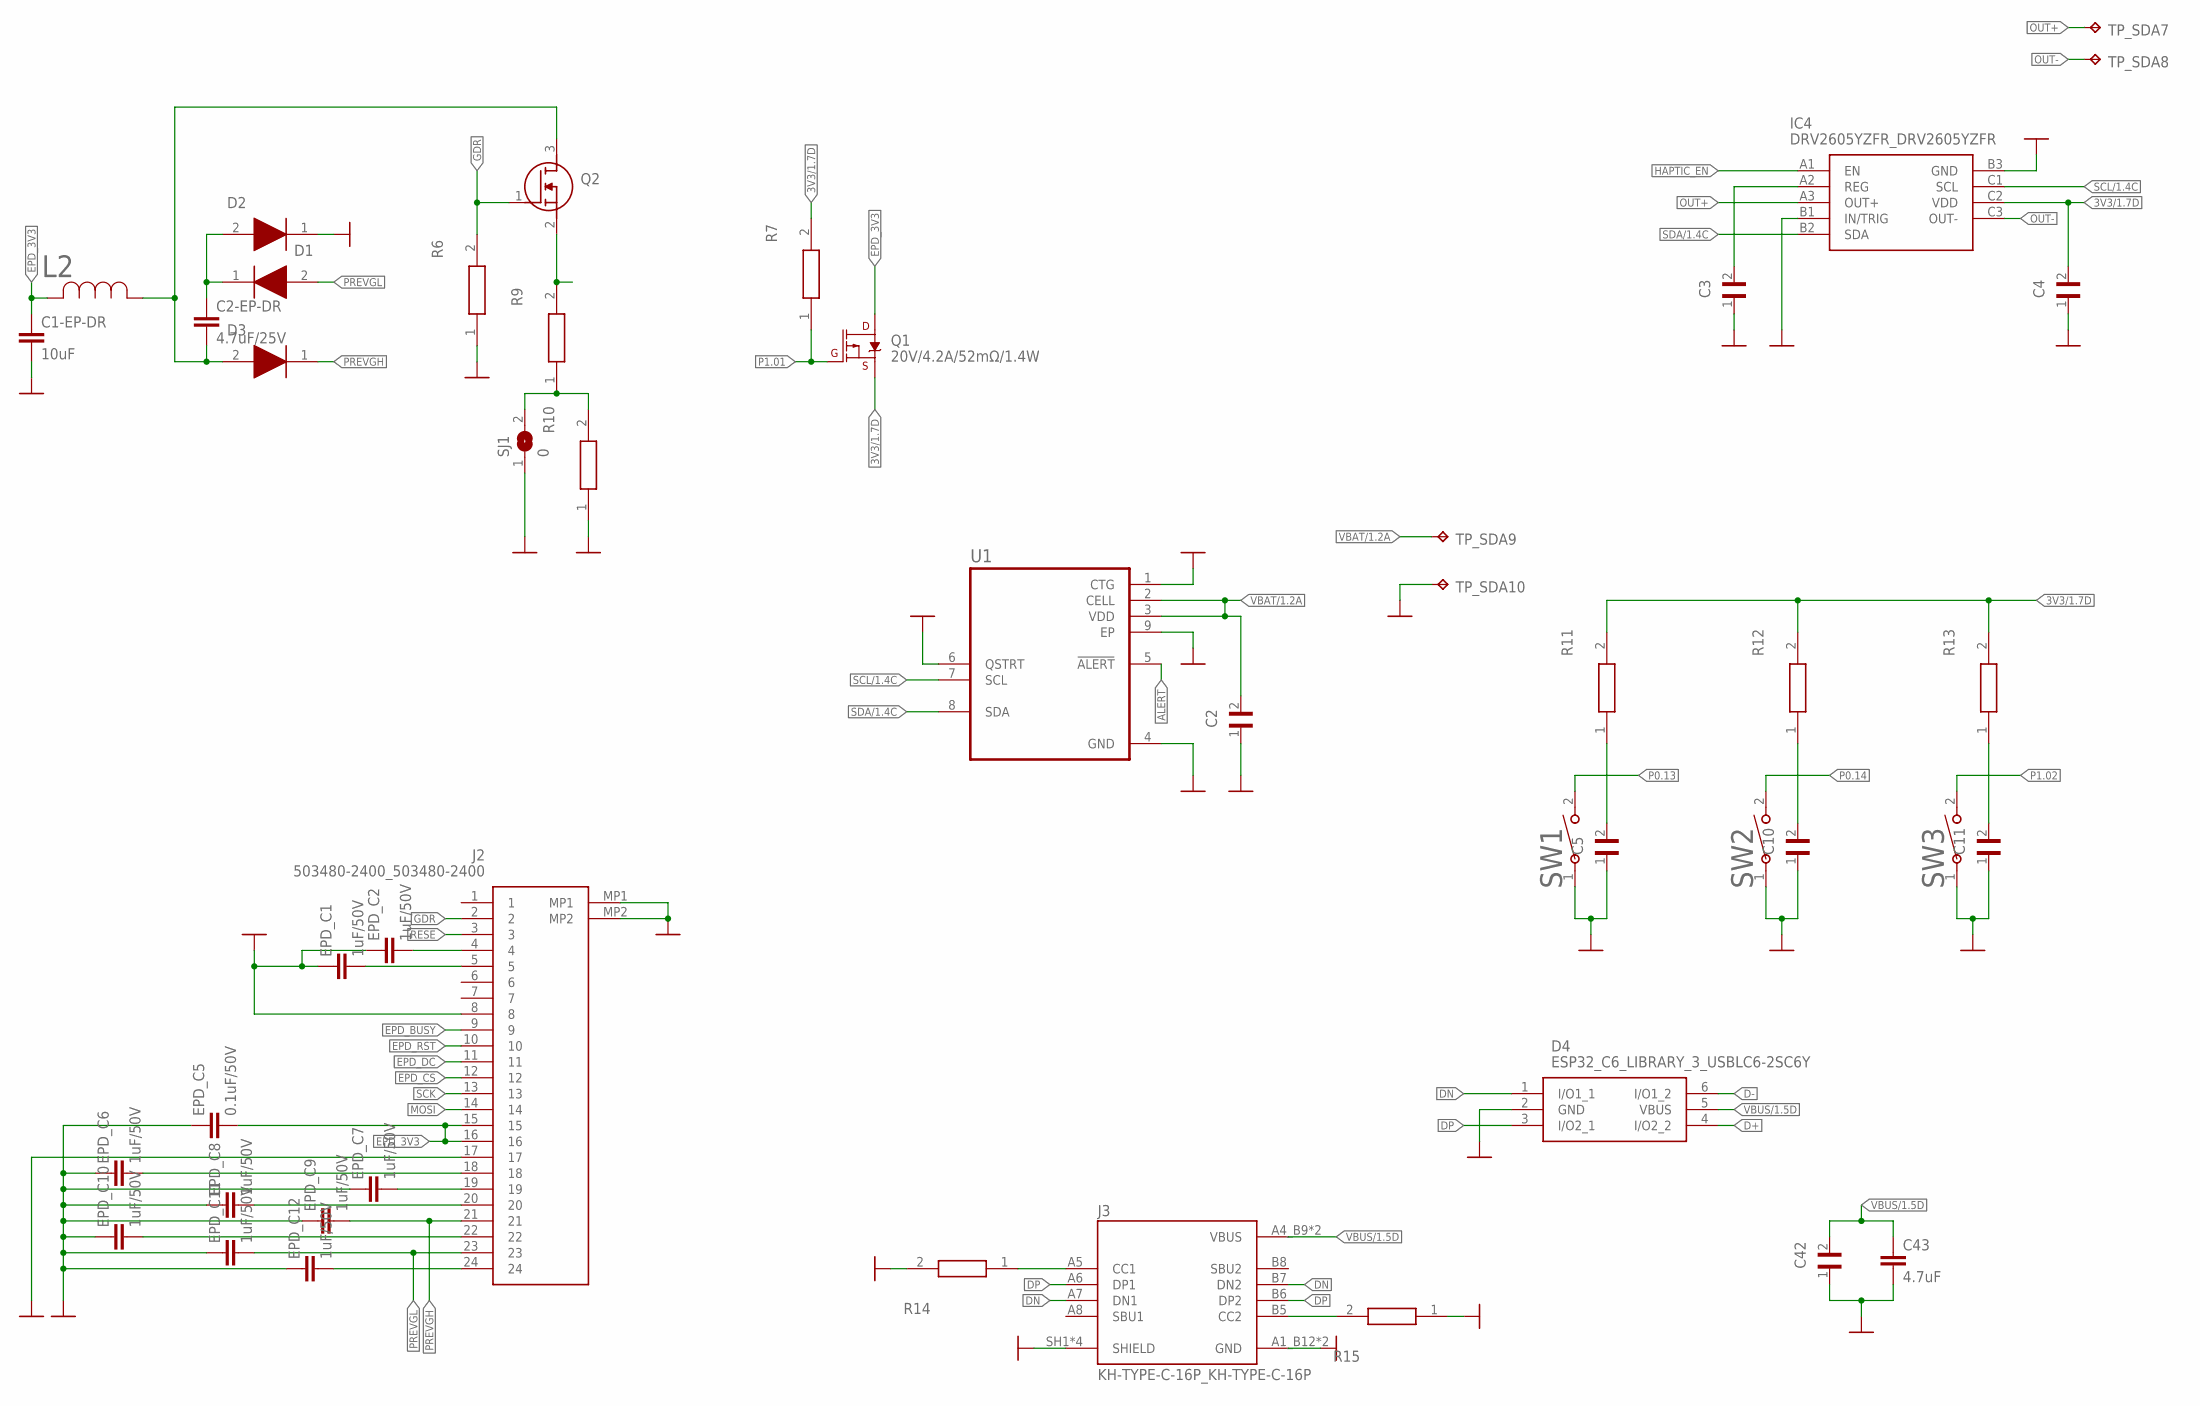
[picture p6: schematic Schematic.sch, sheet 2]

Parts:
C1-EP-DR: 10uF; NORDIC_NRF_3_RESC0402_M
C2, C5, C10, C11, C42: GRM011R60J152KE01L_1_GRM011R60J152KE01L; GRM011R60J152KE01L_1_0201
C2-EP-DR: 4.7uF/25V; ESP32_C6_LIBRARY_1_ESP32_WROVER_EAGLE-LTSPICE_C0402
C3: 1uF; GRM011R60J152KE01L_1_0201
C4: 0.1uF; GRM011R60J152KE01L_1_0201
C43: 4.7uF; NORDIC_NRF_3_RESC0402_M
D1, D2, D3: ESP32_C6_LIBRARY_5_MBR0530; ESP32_C6_LIBRARY_5_SOD3716X135N
D4: ESP32_C6_LIBRARY_3_USBLC6-2SC6Y; ESP32_C6_LIBRARY_3_SOT95P280X145-6N
EPD_C1, EPD_C2, EPD_C6, EPD_C7, EPD_C8, EPD_C9, EPD_C10, EPD_C11, EPD_C12: 1uF/50V; NORDIC_NRF_3_RESC0402_M
EPD_C5: 0.1uF/50V; NORDIC_NRF_3_RESC0402_M
IC4: DRV2605YZFR_DRV2605YZFR; DRV2605YZFR_BGA9C50P3X3_144X144X62
J2: 503480-2400_503480-2400; 503480-2400_5034802400
J3: KH-TYPE-C-16P_KH-TYPE-C-16P; KH-TYPE-C-16P_KINGHELM_KH-TYPE-C-16P
L2: ESP32_C6_LIBRARY_2_744043680IND_4828-WE-TPC_WRE; ESP32_C6_LIBRARY_2_IND_4828-WE-TPC_WRE
Q1: 20V/4.2A/52mΩ/1.4W; ESP32_C6_LIBRARY_4_ESP32_C6_LIBRARY_4_ESP32_C6_LIBRARY_4_ES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
Q2: ESP32_C6_LIBRARY_6_SI1308EDL-T1-GE3; ESP32_C6_LIBRARY_6_SOT65P210X110-3N
R6, R7, R9, R10, R11, R12, R13, R14, R15: CPF0201D7K68C1_CPF0201D7K68C1; CPF0201D7K68C1_0201
SJ1: 0; ESP32_C6_LIBRARY_7_JUMPER_SJ
SW1, SW2, SW3: 2025-10-22_07-23-44_LIBRARY_EVP-AKE31ASW_EVP-AKE3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; 2025-10-22_07-23-44_LIBRARY_SW_EVP-AKE31A_PAN
TP_SDA7, TP_SDA8, TP_SDA9, TP_SDA10: HECTOR_WATCH_1_TPTP20R; HECTOR_WATCH_1_TP20R
U1: ESP32_C6_LIBRARY_MAX17048G+T10; ESP32_C6_LIBRARY_SON50P200X200X80-9N

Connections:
3V3/1.7D: C4.2, IC4.C2 (VDD), Q1.2 (S), R7.2, R11.2, R12.2, R13.2
ALERT: U1.5 (!ALERT); also elsewhere on the board
D+: D4.4 (I/O2_2); also elsewhere on the board
D-: D4.6 (I/O1_2); also elsewhere on the board
DN: D4.1 (I/O1_1), J3.A7 (DN1), J3.B7 (DN2)
DP: D4.3 (I/O2_1), J3.A6 (DP1), J3.B6 (DP2)
EPD_3V3: C1-EP-DR.1, EPD_C5.2, J2.15, J2.16, L2.2, Q1.3 (D)
EPD_BUSY: J2.9; also elsewhere on the board
EPD_CS: J2.12; also elsewhere on the board
EPD_DC: J2.11; also elsewhere on the board
EPD_RST: J2.10; also elsewhere on the board
GDR: J2.2, Q2.1 (G), R6.2
GND: C1-EP-DR.2, C2.1, C3.1, C4.1, C5.1, C10.1, C11.1, C42.1, C43.2, D2.1 (K), D4.2 (GND), EPD_C1.1, EPD_C2.1, EPD_C5.1, EPD_C6.1, EPD_C7.1, EPD_C8.1, EPD_C9.1, EPD_C10.1, EPD_C11.1, EPD_C12.1, IC4.B1 (IN/TRIG), IC4.B3 (GND), J2.8, J2.17, J2.MP1, J2.MP2, J3.A1_B12 (GND), J3.A12_B1 (GND), J3.SH1 (SHIELD), J3.SH2 (SHIELD), J3.SH3 (SHIELD), J3.SH4 (SHIELD), R6.1, R10.1, R14.2, R15.1, SJ1.1, SW1.1, SW2.1, SW3.1, TP_SDA10.TP, U1.1 (CTG), U1.4 (GND), U1.6 (QSTRT), U1.9 (EP); also elsewhere on the board
HAPTIC_EN: IC4.A1 (EN); also elsewhere on the board
MOSI: J2.14; also elsewhere on the board
unnamed: C2-EP-DR.1, D1.1 (K), D2.2 (A)
unnamed: Q2.2 (S), R9.2
unnamed: R9.1, R10.2, SJ1.2
unnamed: C2-EP-DR.2, D3.2 (A), L2.1, Q2.3 (D)
unnamed: EPD_C2.2, J2.4
unnamed: EPD_C1.2, J2.5
unnamed: J3.B5 (CC2), R15.2
unnamed: EPD_C7.2, J2.19
unnamed: C5.2, R11.1
unnamed: EPD_C12.2, J2.24
unnamed: EPD_C6.2, J2.18
unnamed: EPD_C8.2, J2.20
unnamed: C10.2, R12.1
unnamed: EPD_C10.2, J2.22
unnamed: C11.2, R13.1
unnamed: J3.A5 (CC1), R14.1
unnamed: C3.2, IC4.A2 (REG)
OUT+: IC4.A3 (OUT+), TP_SDA7.TP
OUT-: IC4.C3 (OUT-), TP_SDA8.TP
P0.13: SW1.2; also elsewhere on the board
P0.14: SW2.2; also elsewhere on the board
P1.01: Q1.1 (G), R7.1; also elsewhere on the board
P1.02: SW3.2; also elsewhere on the board
PREVGH: D3.1 (K), EPD_C9.2, J2.21
PREVGL: D1.2 (A), EPD_C11.2, J2.23
RESE: J2.3
SCK: J2.13; also elsewhere on the board
SCL/1.4C: IC4.C1 (SCL), U1.7 (SCL)
SDA/1.4C: IC4.B2 (SDA), U1.8 (SDA)
VBAT/1.2A: C2.2, TP_SDA9.TP, U1.2 (CELL), U1.3 (VDD)
VBUS/1.5D: C42.2, C43.1, D4.5 (VBUS), J3.A4_B9 (VBUS), J3.A9_B4 (VBUS)

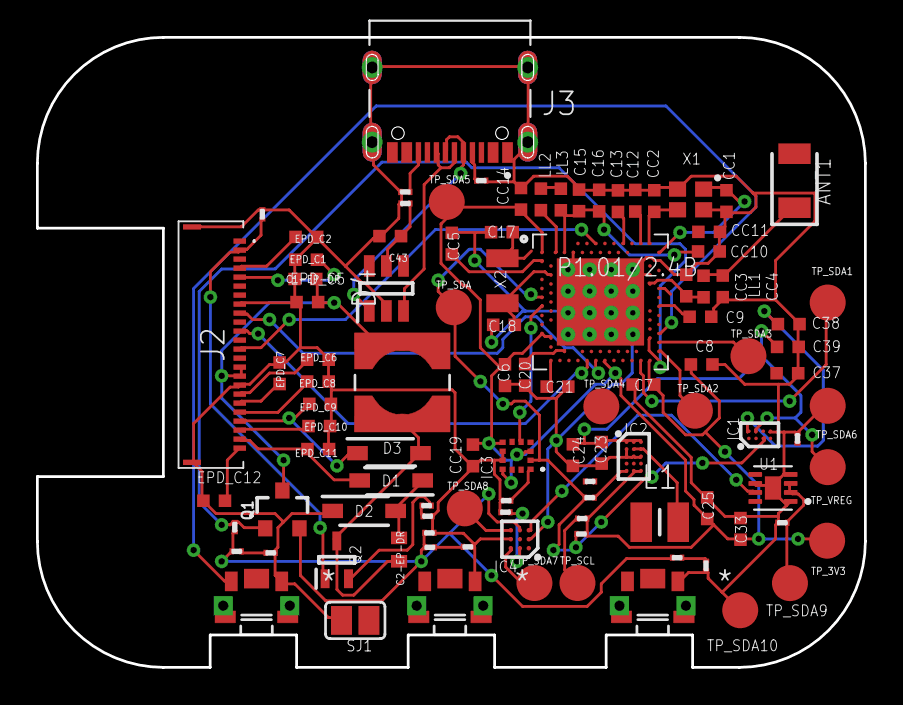
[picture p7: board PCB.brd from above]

Board: 2 copper layers, 46.0 x 35.0 mm, 103 parts (0 on the bottom side), 79 nets.

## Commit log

2026-04-10 first deadline
    [Schematic.brd, Schematic.sch]
2026-04-19 project done
    [PCB.csv, PnP_PCB_front.csv]

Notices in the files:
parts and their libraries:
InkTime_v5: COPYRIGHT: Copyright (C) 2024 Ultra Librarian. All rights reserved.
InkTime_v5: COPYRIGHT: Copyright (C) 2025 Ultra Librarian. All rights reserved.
